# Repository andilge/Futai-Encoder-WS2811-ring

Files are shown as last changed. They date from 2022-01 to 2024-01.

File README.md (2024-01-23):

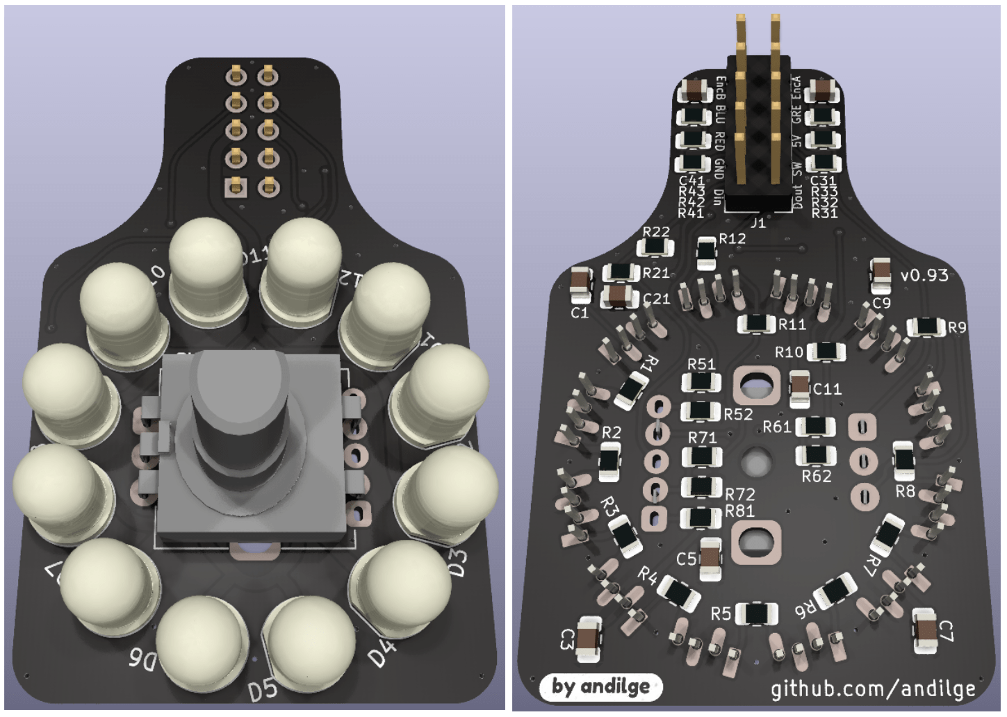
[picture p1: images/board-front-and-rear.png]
The PCB


# A sparkfun enlighted RGB rotary encoder and a ring of 12 WS2811 F5 LEDs behind a translucent blank cover panel
The ultimate DIY human light controller interface plenty of colored LEDs.

## Credits
Inspired by [isotope-engineering's RGB rotary encoder](https://github.com/isotope-engineering/RGB-Encoder-Board "isotope-engineering's RGB rotary encoder").

Shoutout to [ezcGman](https://github.com/ezcGman "ezcGman") for the assistance with the KiCad symbols and footprints, hints about thermal reliefs on pads and the continuous feedback about his experiences while building up the circuit with the board.

## KiCad dependencies
This project uses custom KiCad symbols and footprints and 3D models. Follow folder 'libs' with all details.

## Parts list
The folder 'fabrication' contains the zipped production files for pcb ordering and interactive bill of material ibom.html with purchase links for the components.

Additional to this you can purchase 10 blank cover panels on [aliexpress.com](https://www.aliexpress.com/item/32884601740.html "aliexpress.com")

### SPECIAL ATTENTION REQUIRED !
*There are reports about wrong pin out for the addressable LEDs (D1-D12)*

The [official data sheet from the producer](http://cn.world-semi.com/DownLoadFile/98 "official data sheet from the producer") says
|  pin # | description |
|:---:|:---:|
| 1 | DOUT |
| 2 | VCC |
| 3 | GND |
| 4 | DIN |

With the purchase URL in the BOM, you might get LEDs with 180 degree flipped around pin out
|  pin # | description |
|:---:|:---:|
| 1 | DIN |
| 2 | GND |
| 3 | VCC |
| 4 | DOUT |

If you solder these faulty LEDs on the board "the right way around" the following will happen:
No light turns on and the LEDs instantly burn off to nirvana, some with, others without magic smoke :astonished: rip

The board continues following the LED's specification and can handle these faulty LEDs if you just place them "the wrong way around". Basically, flipped pins together with flipped placement turns out as success again :man_facepalming:.

**IMPORTANT**: Please test a LED from the sent bunch first to get a reality approach about which way around you should use them !

Special thanks to [ezcGman](https://github.com/ezcGman "ezcGman") for burning time and components to achieve this particular insight.

## Connector pinout
| silkscreen | description |
|:---:|---|
| 5V | 5 Volt |
| GND | Ground |
| EncA | Encoder A |
| EncB | Encoder B |
| SW | Switch. On pressing the switch, 3.3 Volt are being passed to this header pin. |
| RED | High voltage level red channel for the rotary encoder LED. *See more information below ! |
| GRE | High voltage level green channel for the rotary encoder LED. *See more information below ! |
| BLU | High voltage level blue channel for the rotary encoder LED. *See more information below !  |
| Din | Data bus in for the adressable LEDs |
| Dout | Data bus out for the adressable LEDs |

*For compatibility reasons with RGB strips, the board exptects 24V (also dimmed with pwm) at the rgb pin headers. If you're driving your **strip with 12V**, please change the value for **R51, R61 and R71 to 5.1kΩ**.
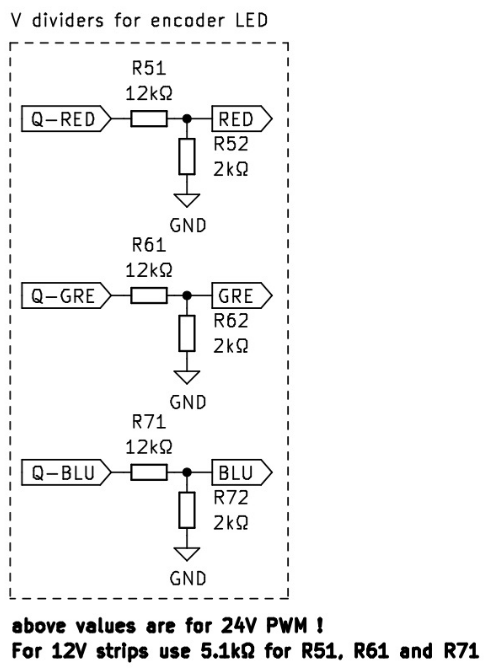
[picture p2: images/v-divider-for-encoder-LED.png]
Voltage dividers for encoder LED


## Schematic
Dive deeper into technical details in the folder 'datasheets-and-schematic'.

## Tools list
### Required
- A soldering iron
- Solder

### Optional
- For SMD components and addressable LEDs:
  - A hot air soldering/re-flow station. However, the smallest parts are 0805 SMD components which can be soldered with a soldering iron. The LED's legs are very close together and easier to solder with hot air.
  - Solder paste
- Tweezers
- The famous IKEA cork coaster (Onderzetter) that gently takes up the heat of your soldering tools.

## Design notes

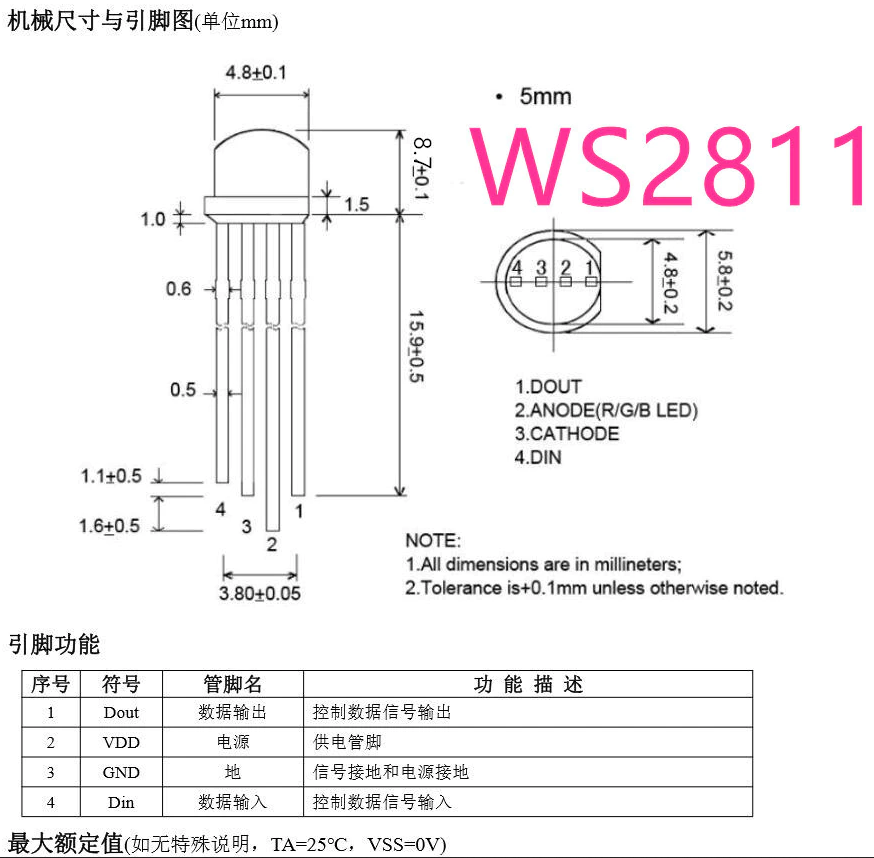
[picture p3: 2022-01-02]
datasheets-and-schematic/ws2811 tht led footprint declaration.png

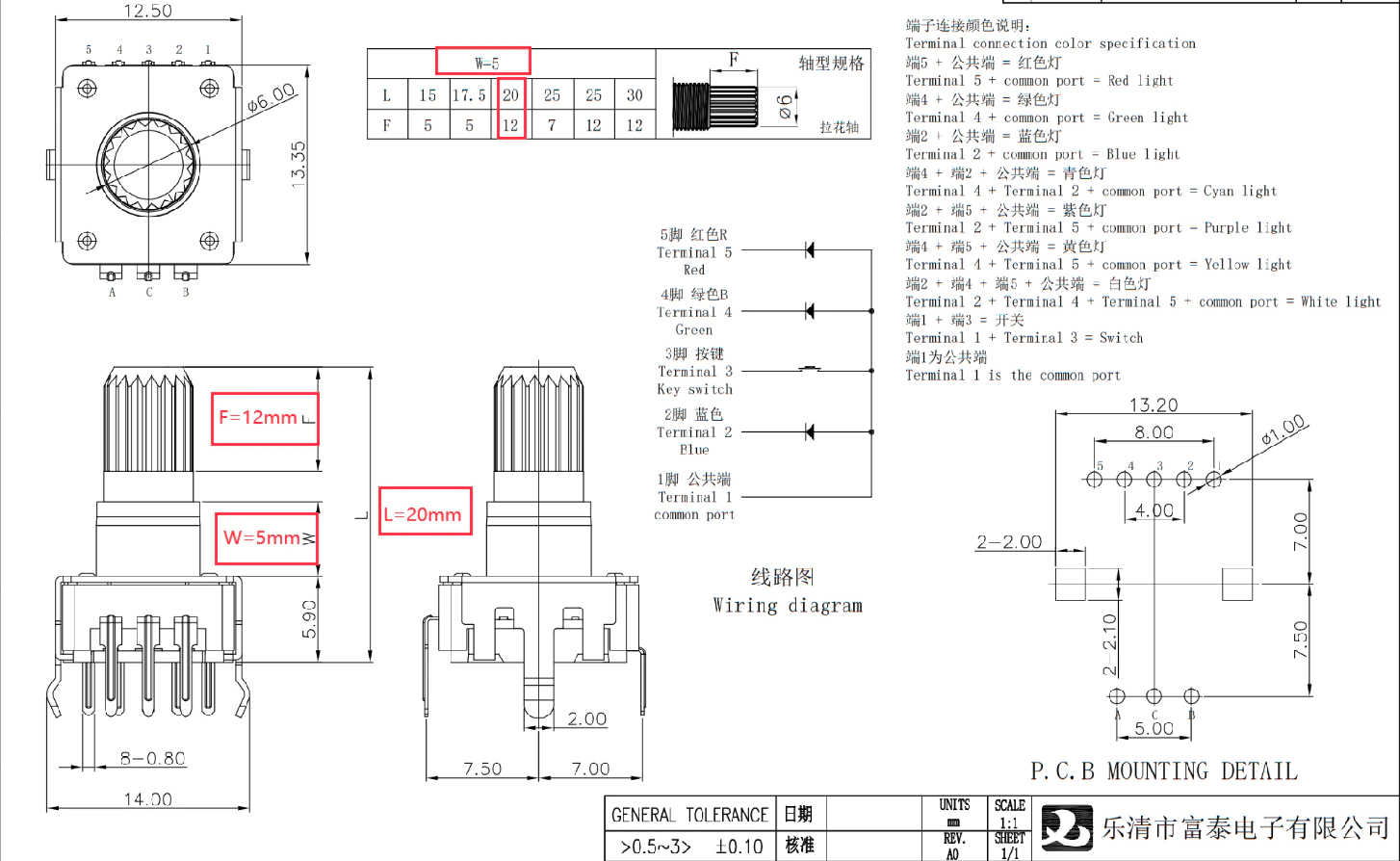
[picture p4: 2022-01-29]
datasheets-and-schematic/futani rotary encoder.png

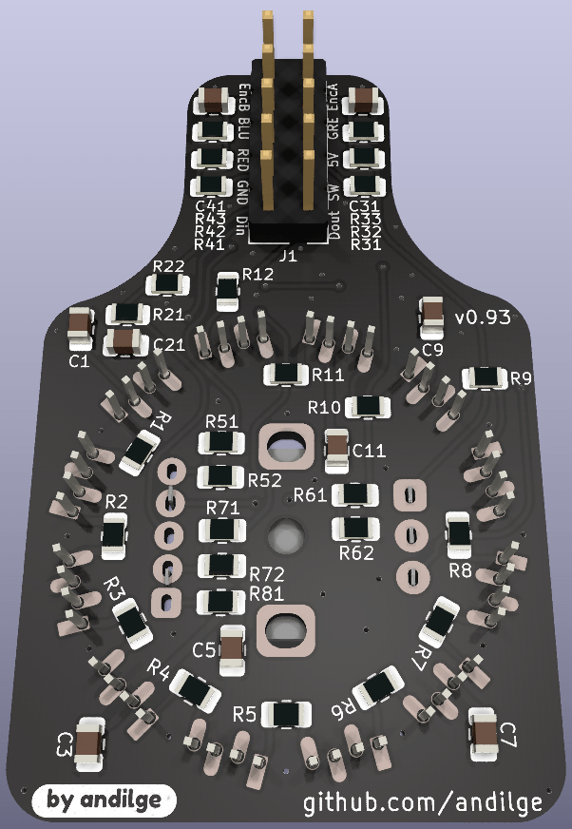
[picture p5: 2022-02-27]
images/board-rear.png

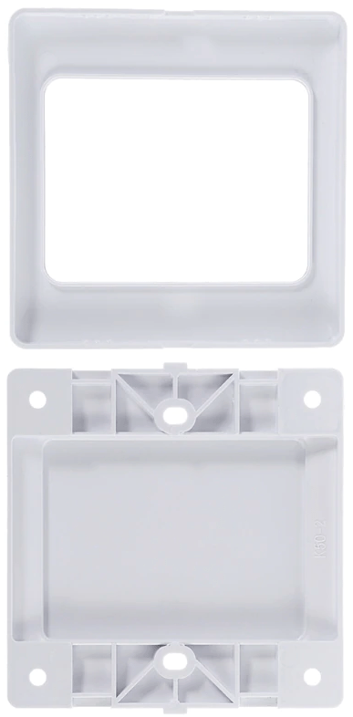
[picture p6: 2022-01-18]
images/blank-cover-panel.png

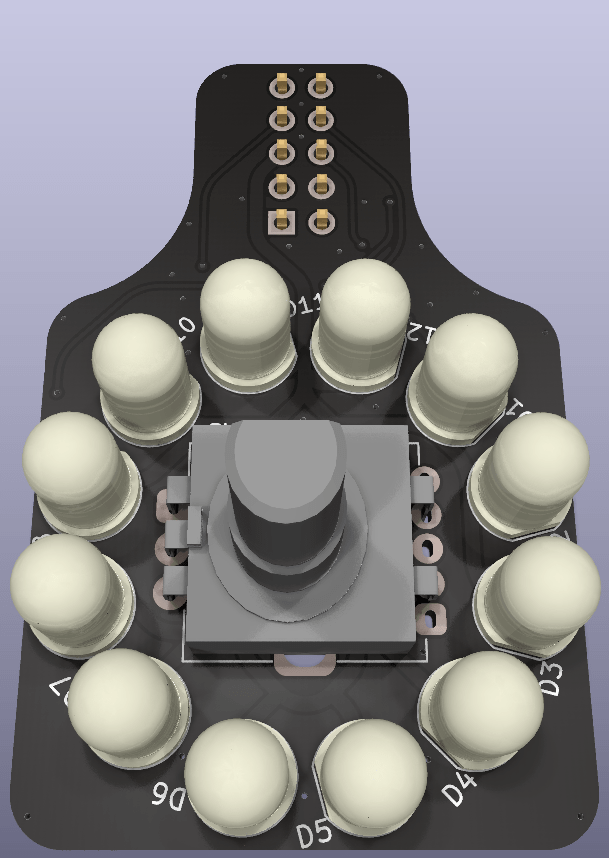
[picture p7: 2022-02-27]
images/board-front.png

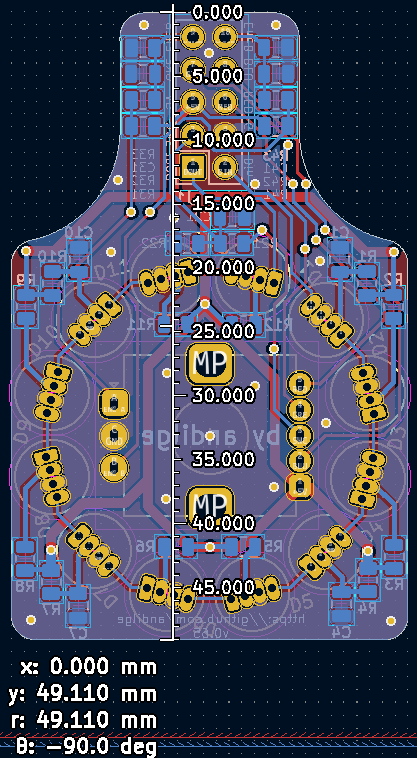
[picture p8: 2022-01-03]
dimensions/y-edge-2-edge.png

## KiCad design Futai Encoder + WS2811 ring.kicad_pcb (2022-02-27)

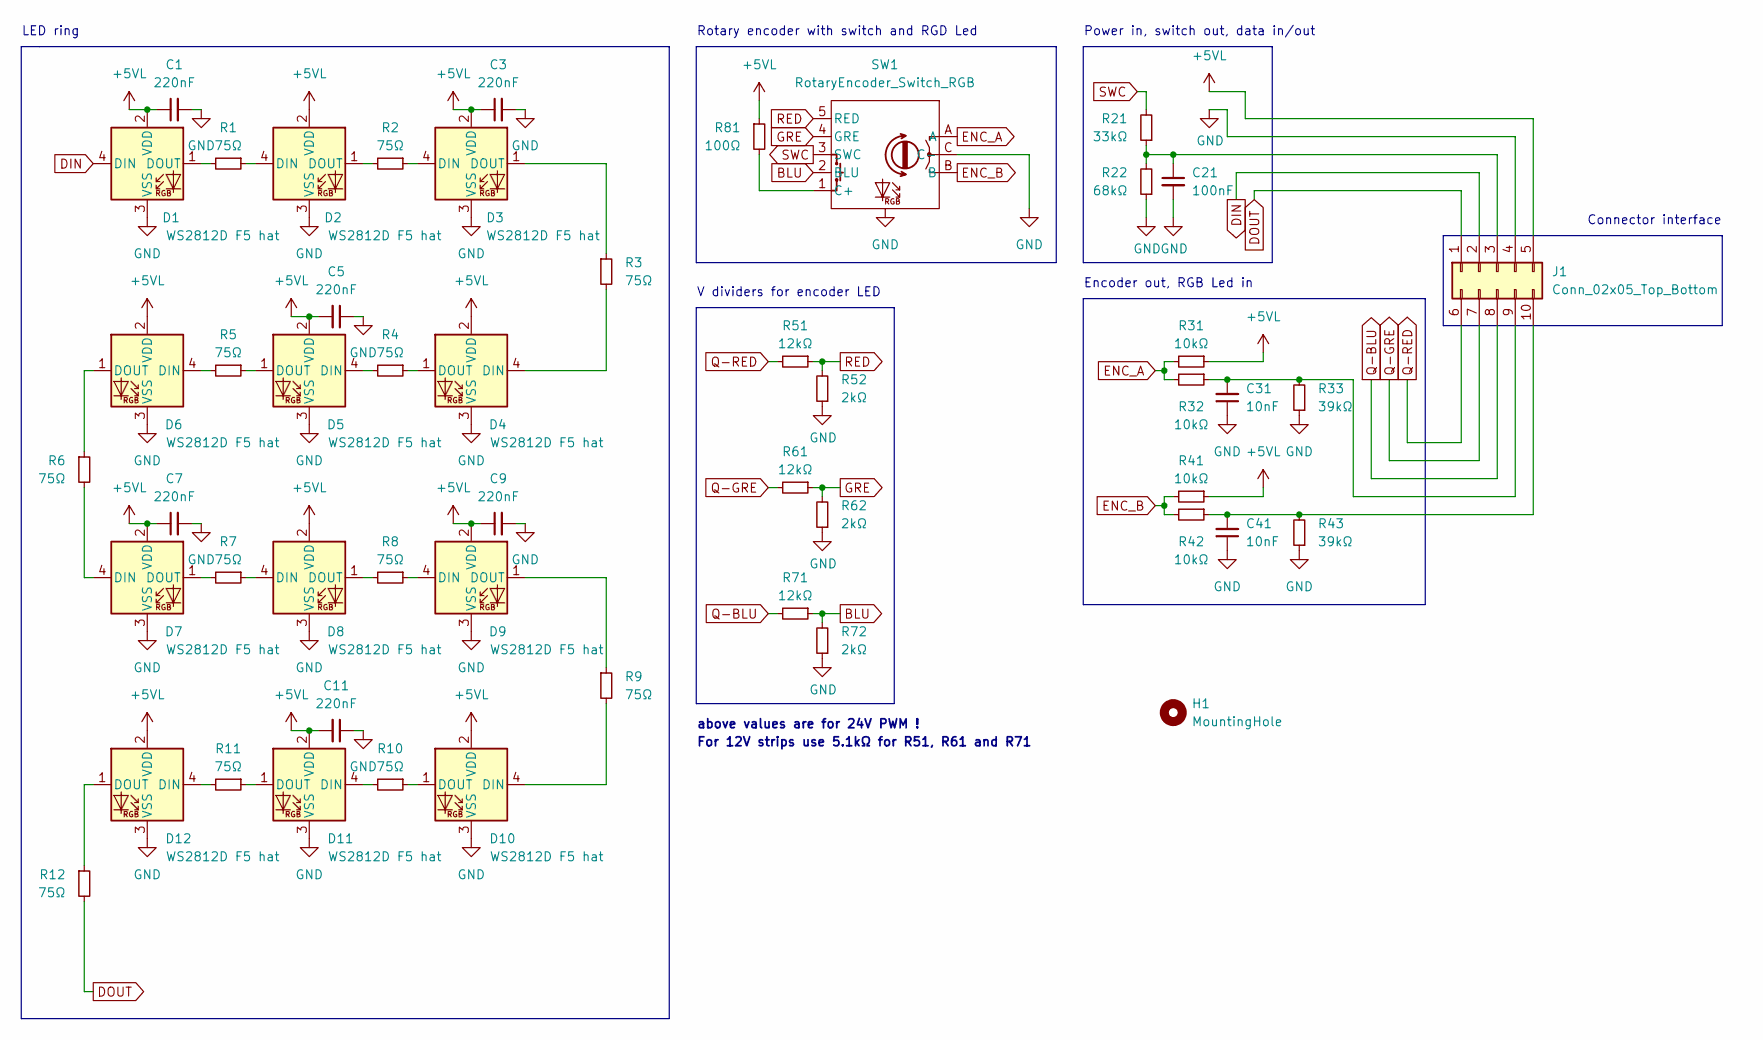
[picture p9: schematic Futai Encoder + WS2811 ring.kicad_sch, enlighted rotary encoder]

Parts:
C1, C3, C5, C7, C9, C11: 220nF; C_0805_2012Metric
C21: 100nF; C_0805_2012Metric
C31, C41: 10nF; C_0805_2012Metric
D1, D2, D3, D4, D5, D6, D7, D8, D9, D10, D11, D12: WS2812D F5 hat; WS2811D-F5-1261
H1: MountingHole; MountingHole_2.2mm_M2
J1: Conn_02x05_Top_Bottom; PinHeader_2x05_P2.54mm_Vertical
R1, R2, R3, R4, R5, R6, R7, R8, R9, R10, R11, R12: 75Ω; R_0805_2012Metric
R21: 33kΩ; R_0805_2012Metric
R22: 68kΩ; R_0805_2012Metric
R31, R32, R41, R42: 10kΩ; R_0805_2012Metric
R33, R43: 39kΩ; R_0805_2012Metric
R51, R61, R71: 12kΩ; R_0805_2012Metric
R52, R62, R72: 2kΩ; R_0805_2012Metric
R81: 100Ω; R_0805_2012Metric
SW1: RotaryEncoder_Switch_RGB; LED_RotaryEncoder_EC12_Switch_Vertical_H20mm

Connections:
+5VL: C1.1, C3.1, C5.2, C7.1, C9.1, C11.2, D1.2 (VDD), D2.2 (VDD), D3.2 (VDD), D4.2 (VDD), D5.2 (VDD), D6.2 (VDD), D7.2 (VDD), D8.2 (VDD), D9.2 (VDD), D10.2 (VDD), D11.2 (VDD), D12.2 (VDD), J1.5, R31.1, R41.1, R81.1
BLU: R71.1, R72.2, SW1.2 (BLU)
DIN: D1.4 (DIN), J1.2
DOUT: J1.1, R12.2
ENC_A: R31.2, R32.2, SW1.A
ENC_B: R41.2, R42.2, SW1.B
GND: C1.2, C3.2, C5.1, C7.2, C9.2, C11.1, C21.2, C31.1, C41.1, D1.3 (VSS), D2.3 (VSS), D3.3 (VSS), D4.3 (VSS), D5.3 (VSS), D6.3 (VSS), D7.3 (VSS), D8.3 (VSS), D9.3 (VSS), D10.3 (VSS), D11.3 (VSS), D12.3 (VSS), J1.4, R22.1, R33.1, R43.1, R52.1, R62.1, R72.1, SW1.C (C-)
GRE: R61.1, R62.2, SW1.4 (GRE)
unnamed: C21.1, J1.3, R21.1, R22.2
unnamed: C31.2, J1.9, R32.1, R33.2
unnamed: C41.2, J1.10, R42.1, R43.2
unnamed: D1.1 (DOUT), R1.2
unnamed: D2.1 (DOUT), R2.2
unnamed: D2.4 (DIN), R1.1
unnamed: D3.1 (DOUT), R3.1
unnamed: D3.4 (DIN), R2.1
unnamed: D4.1 (DOUT), R4.1
unnamed: D4.4 (DIN), R3.2
unnamed: D5.1 (DOUT), R5.1
unnamed: D5.4 (DIN), R4.2
unnamed: D6.1 (DOUT), R6.1
unnamed: D6.4 (DIN), R5.2
unnamed: D7.1 (DOUT), R7.2
unnamed: D7.4 (DIN), R6.2
unnamed: D8.1 (DOUT), R8.2
unnamed: D8.4 (DIN), R7.1
unnamed: D9.1 (DOUT), R9.1
unnamed: D9.4 (DIN), R8.1
unnamed: D10.1 (DOUT), R10.1
unnamed: D10.4 (DIN), R9.2
unnamed: D11.1 (DOUT), R11.1
unnamed: D11.4 (DIN), R10.2
unnamed: D12.1 (DOUT), R12.1
unnamed: D12.4 (DIN), R11.2
unnamed: R81.2, SW1.1 (C+)
Q-BLU: J1.8, R71.2
Q-GRE: J1.7, R61.2
Q-RED: J1.6, R51.2
RED: R51.1, R52.2, SW1.5 (RED)
SWC: R21.2, SW1.3 (SWC)

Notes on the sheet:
For 12V strips use 5.1kΩ for R51, R61 and R71
LED ring
Rotary encoder with switch and RGD Led
Power in, switch out, data in/out
above values are for 24V PWM !
Encoder out, RGB Led in
V dividers for encoder LED
Connector interface

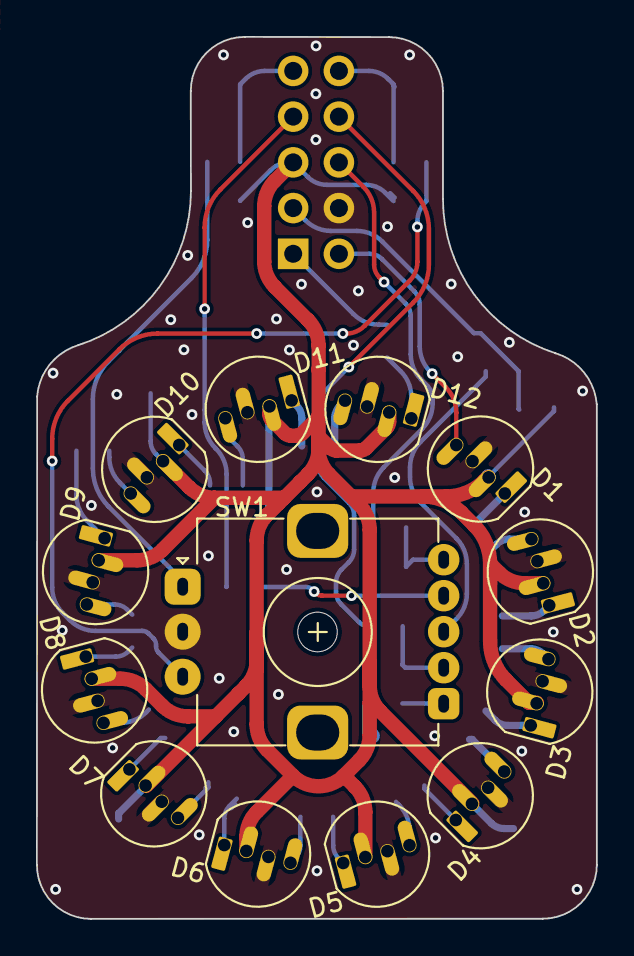
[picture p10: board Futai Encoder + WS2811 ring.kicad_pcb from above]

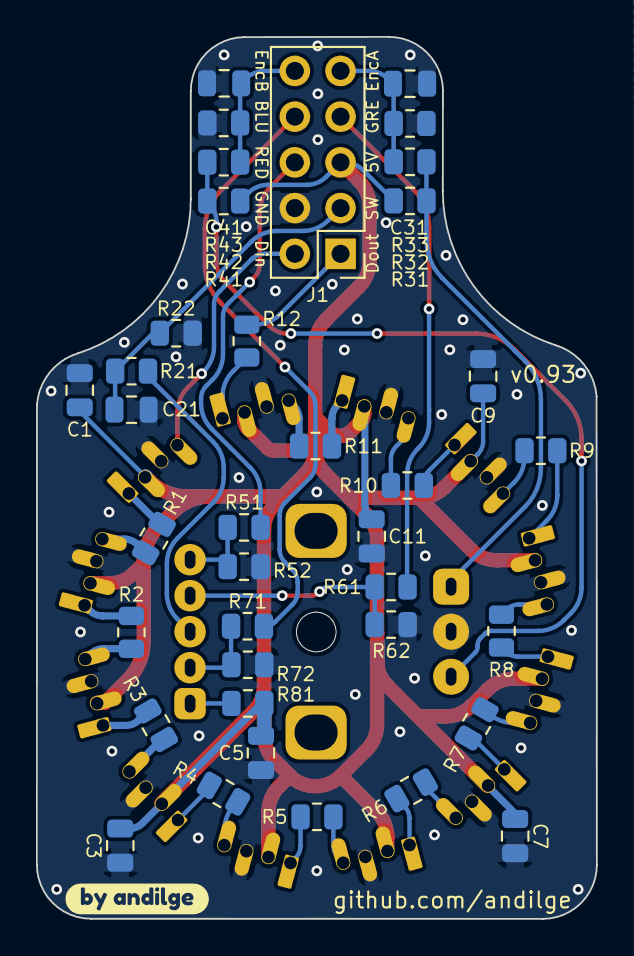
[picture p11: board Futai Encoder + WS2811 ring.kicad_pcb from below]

Board: 2 copper layers, 31.1 x 49.0 mm, 52 parts (38 on the bottom side), 40 nets.

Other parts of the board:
kibuzzard-6202B283: G***; kibuzzard-6202B283

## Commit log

2022-01-02 small cosmetic changes
    [Futai Encoder + WS2811 ring.kicad_pcb]
2022-01-03 smaller board width, new component placements and better track routing
    [Futai Encoder + WS2811 ring.kicad_pcb, Futai Encoder + WS2811 ring.kicad_sch]
2022-01-04 fixing wrong header pin descrition on borad
    [Futai Encoder + WS2811 ring.kicad_pcb]
2022-01-04 completeing 3d models, adding new images
    [Futai Encoder + WS2811 ring.kicad_pcb, Futai Encoder + WS2811 ring.kicad_sch]
2022-01-04 fixing offset on 3ds and new immages
    [Futai Encoder + WS2811 ring.kicad_pcb]
2022-01-04 fixing offset on 3ds and new immages 2
    [Futai Encoder + WS2811 ring.kicad_pcb]
2022-01-04 new 3d for encoder, fixing ibom.html + new images
    [Futai Encoder + WS2811 ring.kicad_pcb, Futai Encoder + WS2811 ring.kicad_sch]
2022-01-18 Clarified the silkscreen to know LED orientation
2022-01-18 adding v0.7
    [Futai Encoder + WS2811 ring.kicad_pcb, Futai Encoder + WS2811 ring.kicad_sch]
2022-01-18 cleaning up old footprint
2022-01-18 adding fabrication files for 0.7
    [Futai Encoder + WS2811 ring.kicad_pcb, Futai Encoder + WS2811 ring.kicad_sch]
2022-01-19 lowering value for R1-R12
    [Futai Encoder + WS2811 ring.kicad_pcb, Futai Encoder + WS2811 ring.kicad_sch]
2022-01-19 small change to value R1-R12
    [Futai Encoder + WS2811 ring.kicad_pcb, Futai Encoder + WS2811 ring.kicad_sch]
2022-01-20 changing name plate to panel in README.md
2022-01-22 better edge cut, adding more info to README.md
    [Futai Encoder + WS2811 ring.kicad_pcb, Futai Encoder + WS2811 ring.kicad_sch]
2022-01-29 encoder with shorter handle
    [Futai Encoder + WS2811 ring.kicad_pcb, Futai Encoder + WS2811 ring.kicad_sch]
2022-01-29 handsolder friendly footprint for LEDs
    [Futai Encoder + WS2811 ring.kicad_pcb]
2022-01-29 new images with the new LEd footpring
2022-01-31 adding M3 hole beneth encoder to mark drill hole on panel
    [Futai Encoder + WS2811 ring.kicad_pcb, Futai Encoder + WS2811 ring.kicad_sch]
2022-02-07 brushing up schematic diagram.pdf
    [Futai Encoder + WS2811 ring.kicad_pcb, Futai Encoder + WS2811 ring.kicad_sch]
2022-02-08 smaller silkscreens, minor changes in trackings
    [Futai Encoder + WS2811 ring.kicad_pcb]
2022-02-10 fixing typo
    [Futai Encoder + WS2811 ring.kicad_pcb, Futai Encoder + WS2811 ring.kicad_sch]
2022-02-24 v0.93, minor routing changes, better gnd zones
    [Futai Encoder + WS2811 ring.kicad_pcb]
2022-02-27 smaller center hole
    [Futai Encoder + WS2811 ring.kicad_pcb, Futai Encoder + WS2811 ring.kicad_sch]
